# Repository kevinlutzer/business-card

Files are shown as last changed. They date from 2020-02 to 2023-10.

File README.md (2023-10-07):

# Electronic Business Card 

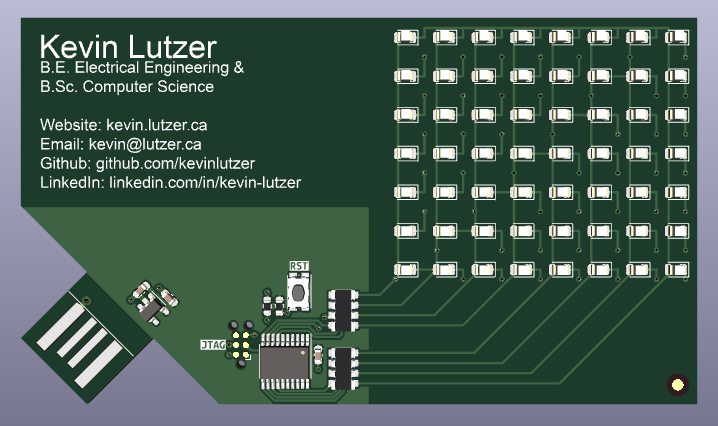
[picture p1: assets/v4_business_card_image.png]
V4 Business Card


The purpose of this project was to demonstrate some of my skills as an Electrical Engineer to potential employers. This project required me to build and prototype a tri-state circuit, add controls with a STM32G ARM microcontroller and design/manufacture a custom printed circuit board. When you plug the device into a standard USB2A port it scrolls my portfolio website's URL across the matrix display. I designed this device to cost about $2.50 CAD per populated board. 

This idea was inspired by a piece of advice that Dave Jones, the owner of the [EEVblog](https://www.eevblog.com/) gave. He suggests that engineers should be bringing something to an interview to show that they can actually design and build things. I sent a later version of this project to Dave Jones with a programmer PCB which he opened on a [Mailbag Segment](https://youtu.be/45C6HFf2kIA?si=SCQMgJs3VvQc_wUq&t=3084). 

Currently I am using the project as a way to test and calibrate a pick and place machine.

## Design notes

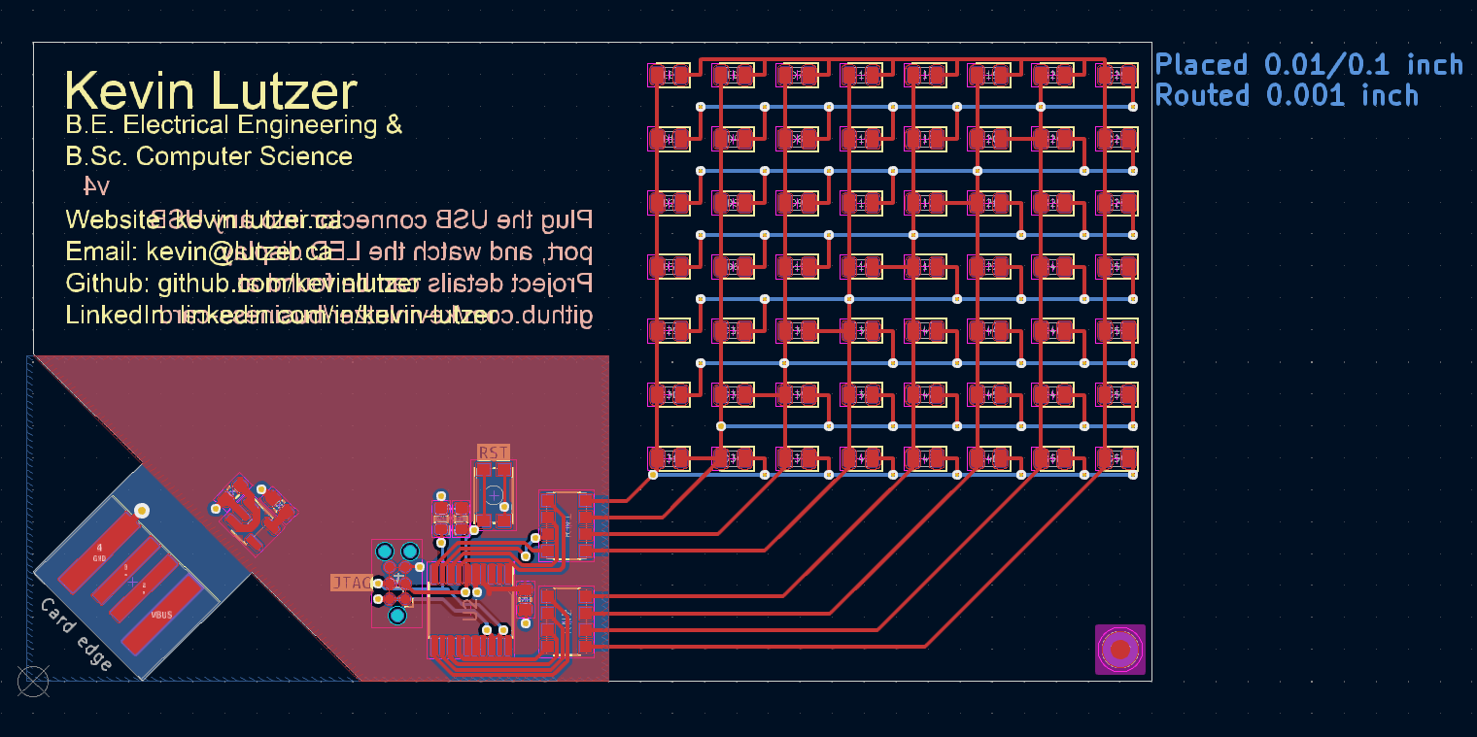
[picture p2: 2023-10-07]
assets/business_card_v4_layout.png

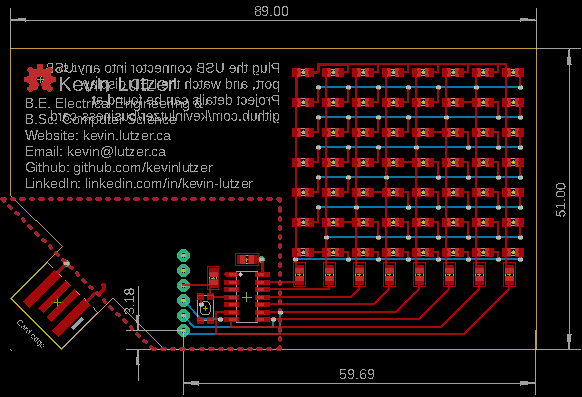
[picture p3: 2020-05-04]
assets/business_card.png

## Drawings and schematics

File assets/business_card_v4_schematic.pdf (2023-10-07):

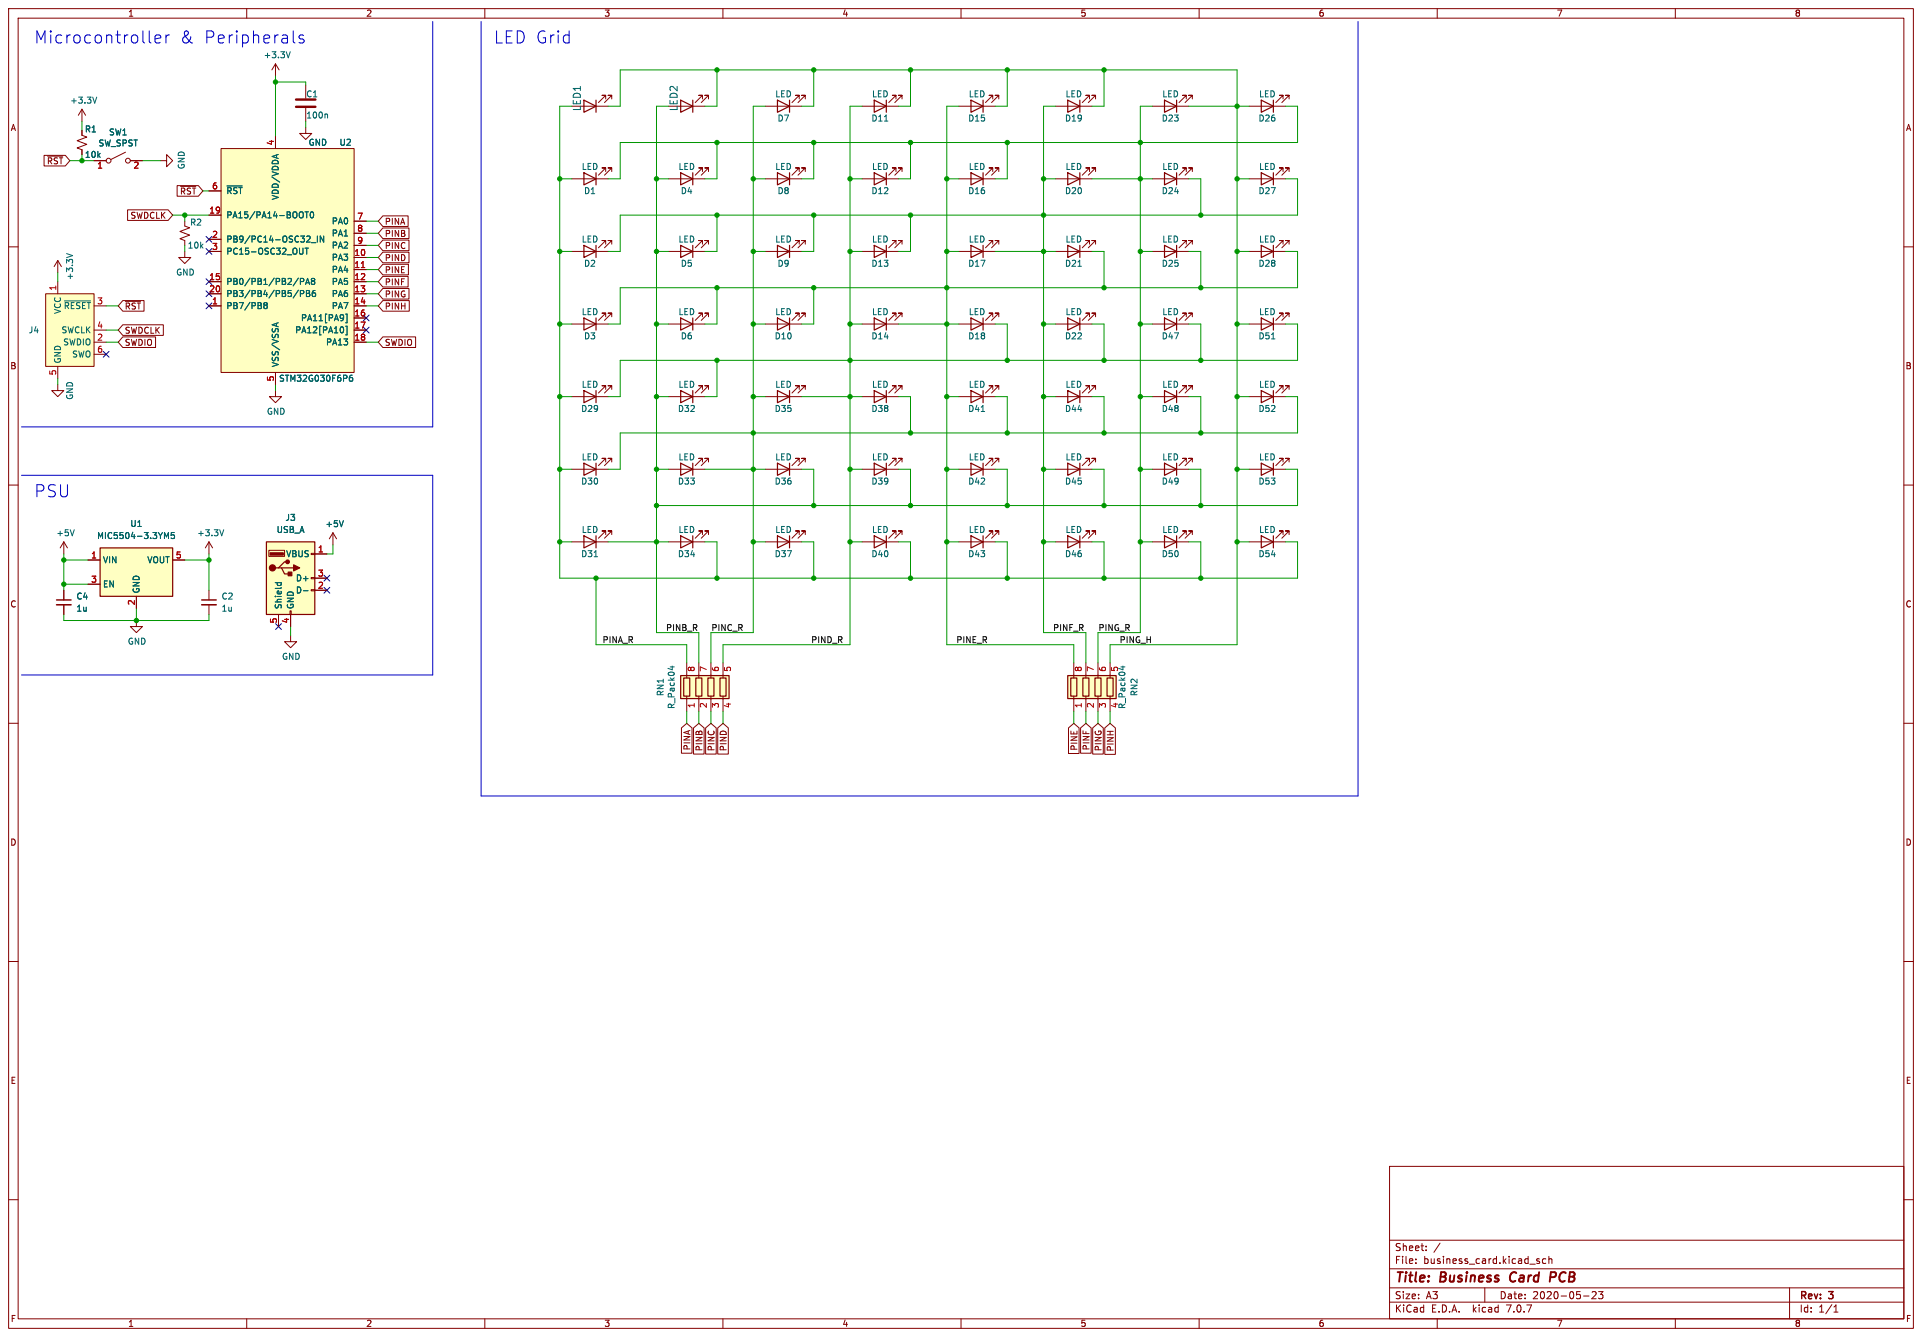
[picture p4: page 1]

1 SWDIO 2 ~{RESET}3 SWCLK 4 GND
LED VCC

Id: 1/1 Title: Business Card PCB

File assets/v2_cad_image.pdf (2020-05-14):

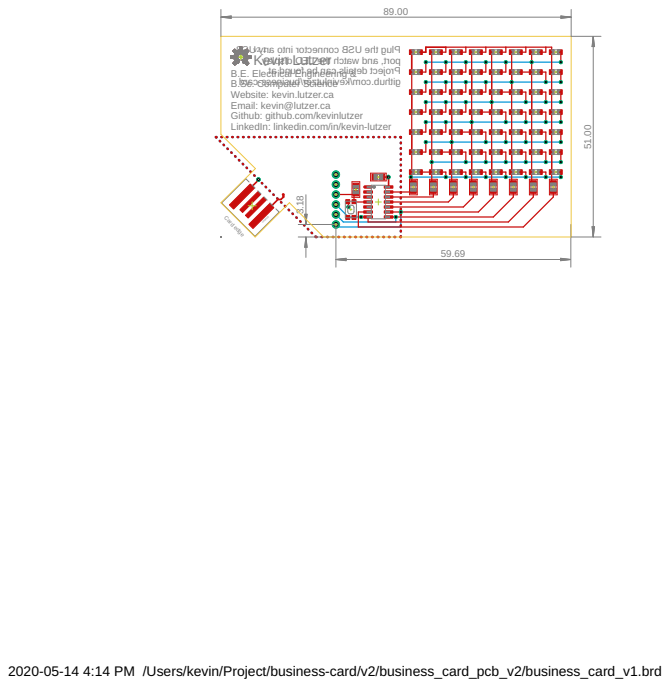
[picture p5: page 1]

B.E. Electrical Engineering &
B.Sc. Computer Science Website: kevin.lutzer.ca Email: kevin@lutzer.ca Github: github.com/kevinlutzer LinkedIn: linkedin.com/in/kevin-lutzer

2020-05-14 4:14 PM /Users/kevin/Project/business-card/v2/business_card_pcb_v2/business_card_v1.brd

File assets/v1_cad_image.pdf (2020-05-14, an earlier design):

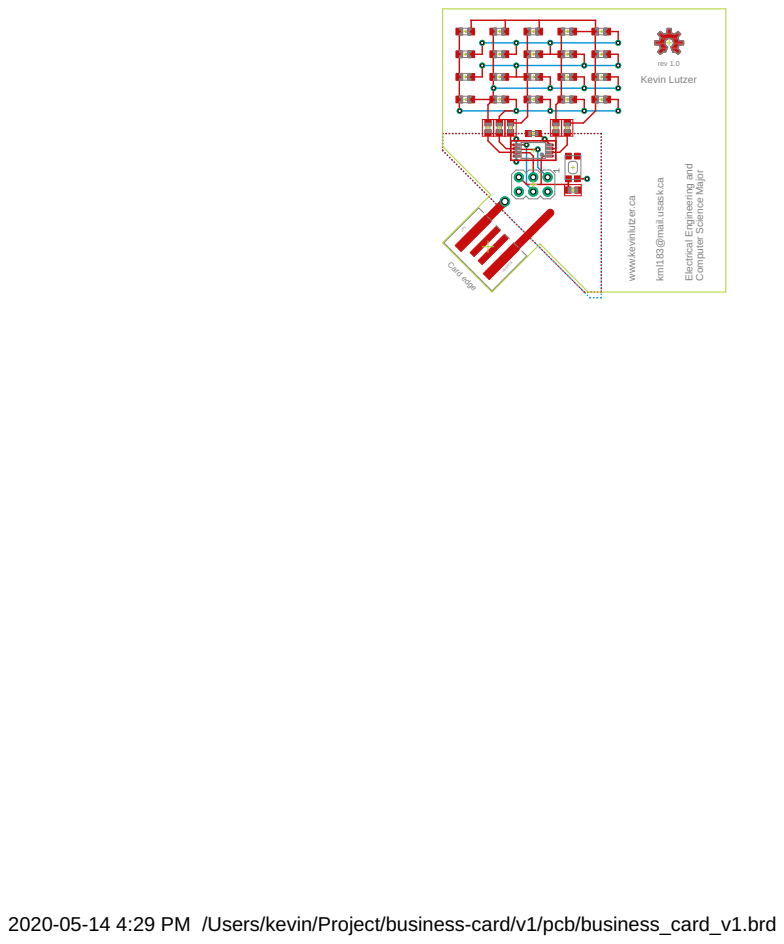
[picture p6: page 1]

kml183@mail.usask.ca Electrical Engineering and Computer Science Major

2020-05-14 4:29 PM /Users/kevin/Project/business-card/v1/pcb/business_card_v1.brd

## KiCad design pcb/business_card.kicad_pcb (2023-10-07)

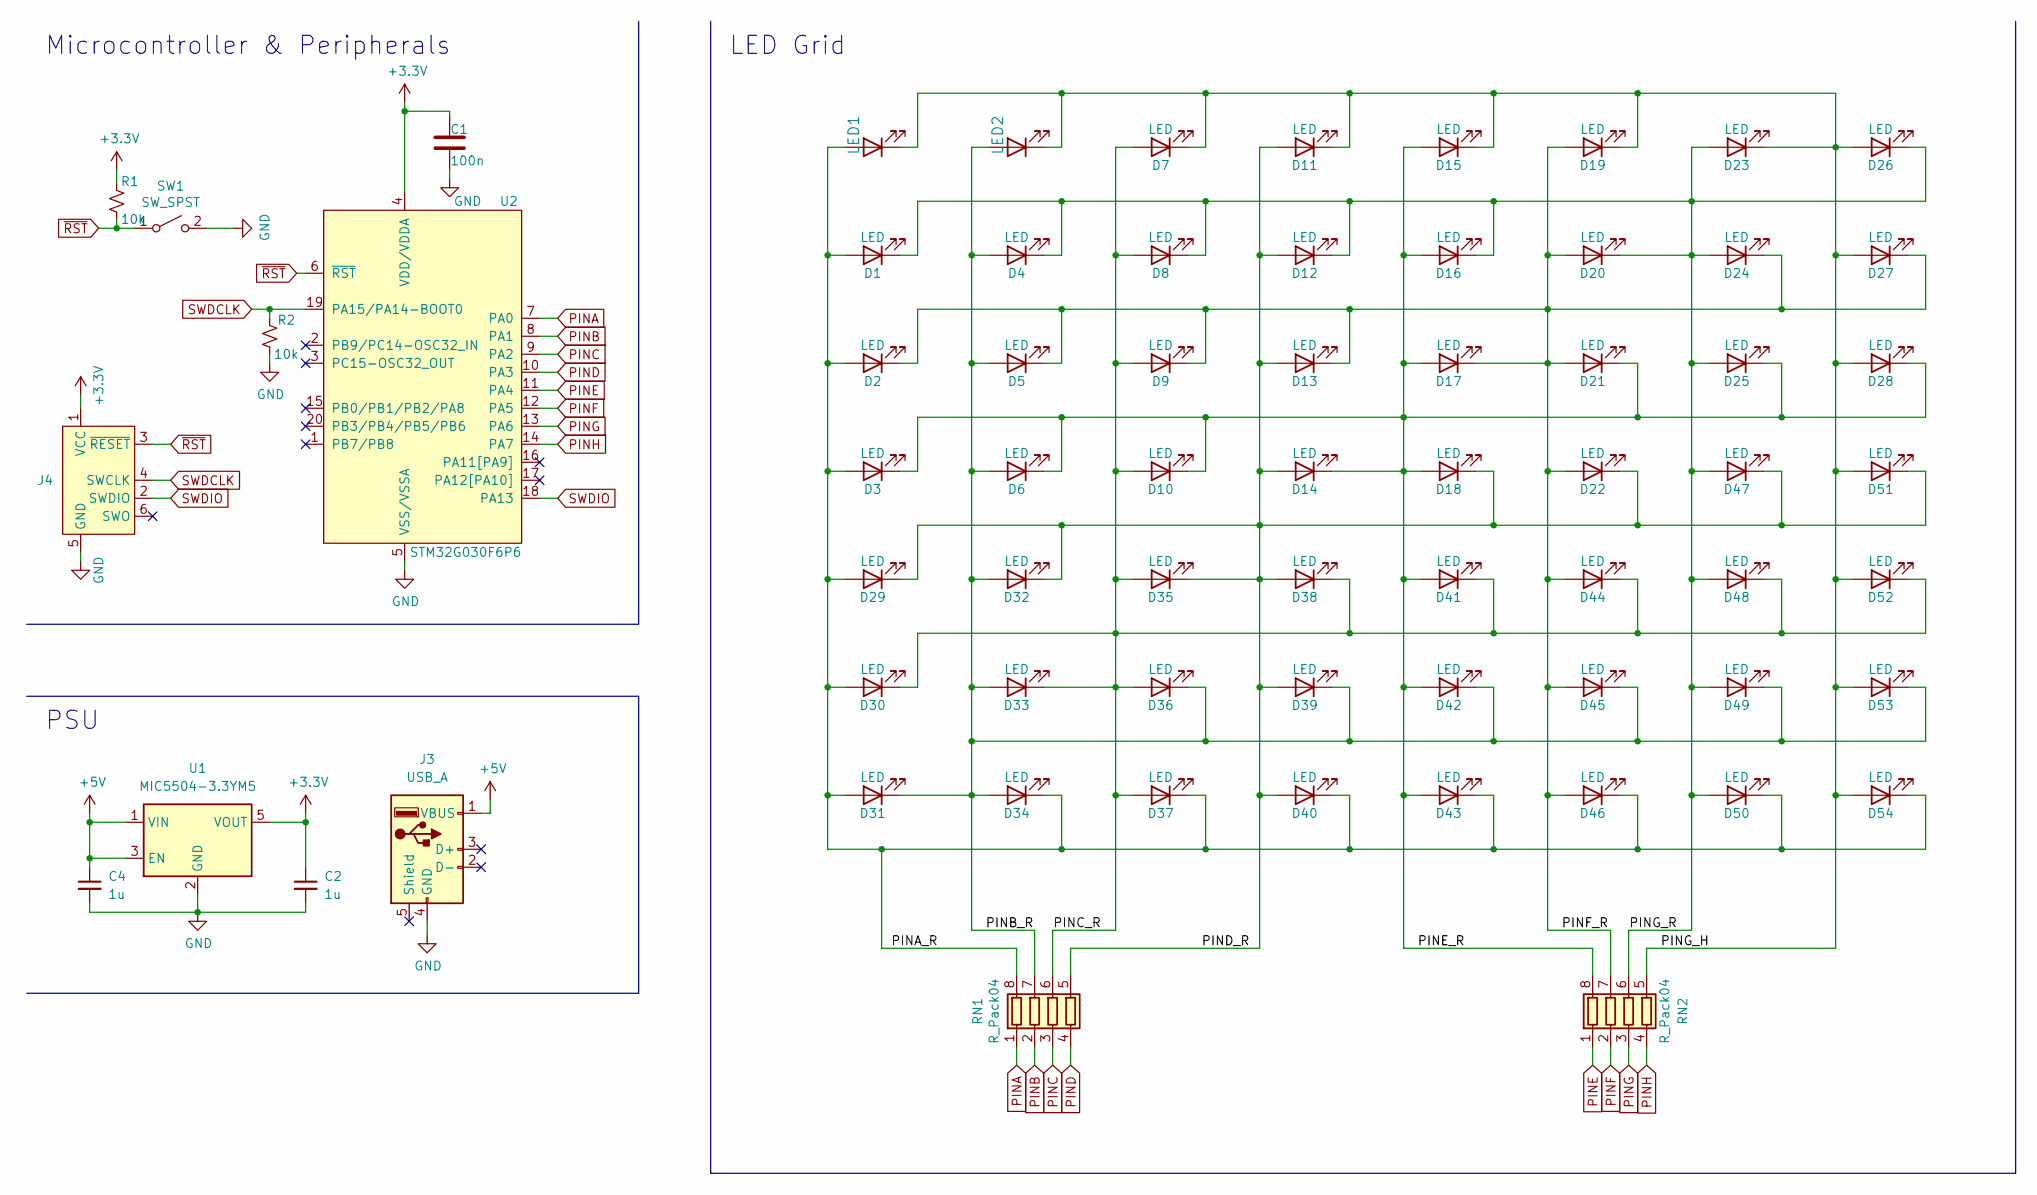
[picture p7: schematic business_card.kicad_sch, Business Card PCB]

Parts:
C1: 100n; C_0603_1608Metric
C2, C4: 1u; C_0603_1608Metric
D1, D2, D3, D4, D5, D6, D7, D8, D9, D10, D11, D12, D13, D14, D15, D16, D17, D18, D19, D20, D21, D22, D23, D24, D25, D26, D27, D28, D29, D30, D31, D32, D33, D34, D35, D36, D37, D38, D39, D40, D41, D42, D43, D44, D45, D46, D47, D48, D49, D50, D51, D52, D53, D54: LED; LED_0805_2012Metric
J3: USB_A; USB_A_PCB
J4: Conn_ARM_SWD_TagConnect_TC2030; Tag-Connect_TC2030-IDC-NL_2x03_P1.27mm_Vertical
LED1: LED; LED_0805_2012Metric
LED2: LED; D_0805_2012Metric
R1, R2: 10k; R_0603_1608Metric
RN1, RN2: R_Pack04; R_Array_Convex_4x1206
SW1: SW_SPST; SW_Push_1P1T_NO_CK_KMR2
U1: MIC5504-3.3YM5; SOT-23-5
U2: STM32G030F6P6; TSSOP-20_4.4x6.5mm_P0.65mm

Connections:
+3V3: C1.1, C2.1, J4.1 (VCC), R1.1, U1.5 (VOUT), U2.4 (VDD/VDDA)
+5V: C4.1, J3.1 (VBUS), U1.1 (VIN), U1.3 (EN)
/PINA_R: D1.2 (A), D2.2 (A), D3.2 (A), D29.2 (A), D30.2 (A), D31.2 (A), D34.1 (K), D37.1 (K), D40.1 (K), D43.1 (K), D46.1 (K), D50.1 (K), D54.1 (K), LED1.2 (A), RN1.8 (R1.2)
/PINB_R: D4.2 (A), D5.2 (A), D6.2 (A), D31.1 (K), D32.2 (A), D33.2 (A), D34.2 (A), D36.1 (K), D39.1 (K), D42.1 (K), D45.1 (K), D49.1 (K), D53.1 (K), LED2.2 (A), RN1.7 (R2.2)
/PINC_R: D7.2 (A), D8.2 (A), D9.2 (A), D10.2 (A), D30.1 (K), D33.1 (K), D35.2 (A), D36.2 (A), D37.2 (A), D38.1 (K), D41.1 (K), D44.1 (K), D48.1 (K), D52.1 (K), RN1.6 (R3.2)
/PIND_R: D11.2 (A), D12.2 (A), D13.2 (A), D14.2 (A), D18.1 (K), D22.1 (K), D29.1 (K), D32.1 (K), D35.1 (K), D38.2 (A), D39.2 (A), D40.2 (A), D47.1 (K), D51.1 (K), RN1.5 (R4.2)
/PINE_R: D3.1 (K), D6.1 (K), D10.1 (K), D14.1 (K), D15.2 (A), D16.2 (A), D17.2 (A), D18.2 (A), D21.1 (K), D25.1 (K), D28.1 (K), D41.2 (A), D42.2 (A), D43.2 (A), RN2.8 (R1.2)
/PINF_R: D2.1 (K), D5.1 (K), D9.1 (K), D13.1 (K), D17.1 (K), D19.2 (A), D20.2 (A), D21.2 (A), D22.2 (A), D24.1 (K), D27.1 (K), D44.2 (A), D45.2 (A), D46.2 (A), RN2.7 (R2.2)
/PING_H: D7.1 (K), D11.1 (K), D15.1 (K), D19.1 (K), D23.1 (K), D26.2 (A), D27.2 (A), D28.2 (A), D51.2 (A), D52.2 (A), D53.2 (A), D54.2 (A), LED1.1 (K), LED2.1 (K), RN2.5 (R4.2)
/PING_R: D1.1 (K), D4.1 (K), D8.1 (K), D12.1 (K), D16.1 (K), D20.1 (K), D23.2 (A), D24.2 (A), D25.2 (A), D26.1 (K), D47.2 (A), D48.2 (A), D49.2 (A), D50.2 (A), RN2.6 (R3.2)
GND: C1.2, C2.2, C4.2, J3.4 (GND), J4.5 (GND), R2.2, SW1.2 (B), U1.2 (GND), U2.5 (VSS/VSSA)
PINA: RN1.1 (R1.1), U2.7 (PA0)
PINB: RN1.2 (R2.1), U2.8 (PA1)
PINC: RN1.3 (R3.1), U2.9 (PA2)
PIND: RN1.4 (R4.1), U2.10 (PA3)
PINE: RN2.1 (R1.1), U2.11 (PA4)
PINF: RN2.2 (R2.1), U2.12 (PA5)
PING: RN2.3 (R3.1), U2.13 (PA6)
PINH: RN2.4 (R4.1), U2.14 (PA7)
SWDCLK: J4.4 (SWCLK), R2.1, U2.19 (PA15/PA14-BOOT0)
SWDIO: J4.2 (SWDIO), U2.18 (PA13)
~RST: J4.3 (~RESET), R1.2, SW1.1 (A), U2.6 (~RST)

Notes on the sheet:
Microcontroller & Peripherals
PSU
LED Grid

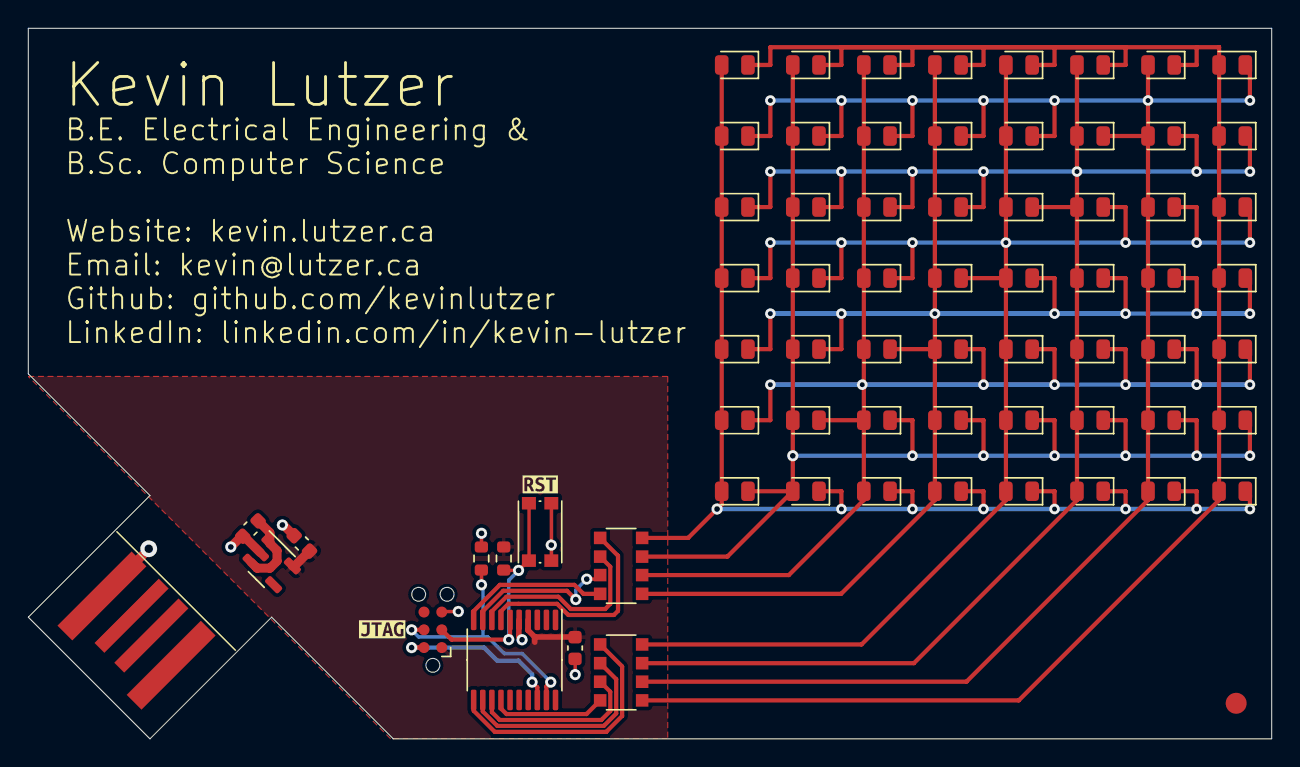
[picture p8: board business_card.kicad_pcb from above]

Board: 2 copper layers, 88.9 x 50.8 mm, 70 parts (0 on the bottom side), 22 nets.

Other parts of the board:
kibuzzard-64BD977B: G***; kibuzzard-64BD977B
kibuzzard-64BD9765: G***; kibuzzard-64BD9765

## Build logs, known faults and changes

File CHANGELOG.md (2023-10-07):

## V4

I added a faducial to the PCB to aid in some experiments I will be running with a pick and place machine. I also swapped out the programming header to use a Tag Connect TC2030 connector footprint. This removes the need for a 0.1 inch programming header or a custom programming PCB. I also switched the design to use a STM32G series process that has an arm core in it. 



## V2

I redesigned the device to use a 7x8 display, this required a larger ATMEL processor as I needed 8 pins to drive the display. Bellow is an image demonstrating what it looks like: 

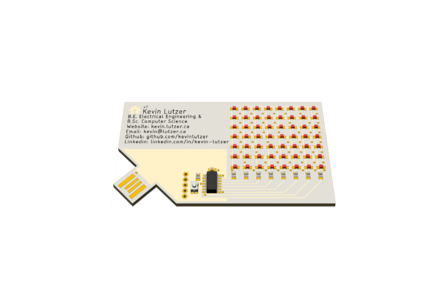
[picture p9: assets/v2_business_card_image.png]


## V1 

The first prototype of this device came in late 2016, early 2017. The image of it operating is below. One of the main problems with this version is that I wasn't able to incorporate the standard 7 bit dot matrix alphabet, so I had to make my own. The result was a display that was hard to read. 

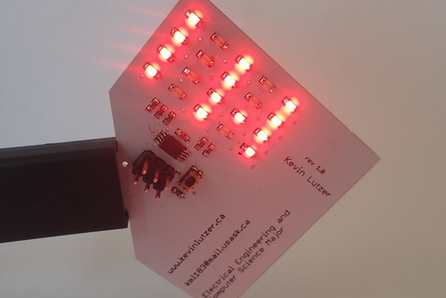
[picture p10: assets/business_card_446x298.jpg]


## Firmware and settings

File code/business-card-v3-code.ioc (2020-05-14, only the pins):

Mcu.UserName=STM32G030F6Px
PA7.Signal=GPIO_Output

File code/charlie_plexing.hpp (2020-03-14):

/*
	Author: Kevin Lutzer
	Created Date: February 3 2016

	Description: Class for controlling a 4X5 led matrix using charlieplexing.
*/

#include <avr/io.h>
#include <util/delay.h>

#define LINEA PA0
#define LINEB PA1
#define LINEC PA2
#define LINED PA3
#define LINEE PA4
#define LINEF PA5
#define LINEG PA6
#define LINEH PA7

#define F_CPU 1000000UL
#define SCROLL_DELAY 100

const uint8_t ncharlieOut[7][8] = {

	// Row 0
	( ( 1 << LINEA ) | ( 0 << LINEH ) ),
	( ( 1 << LINEB ) | ( 0 << LINEH ) ),
	( ( 1 << LINEC ) | ( 0 << LINEH ) ),
	( ( 1 << LINED ) | ( 0 << LINEH ) ),
	( ( 1 << LINEE ) | ( 0 << LINEH ) ),
	( ( 1 << LINEF ) | ( 0 << LINEH ) ), 
	( ( 1 << LINEG ) | ( 0 << LINEH ) ), 
	( ( 1 << LINEH ) | ( 0 << LINEG ) ),

	// Row 1
	( ( 1 << LINEA ) | ( 0 << LINEG ) ),
	( ( 1 << LINEB ) | ( 0 << LINEG ) ),
	( ( 1 << LINEC ) | ( 0 << LINEG ) ),
	( ( 1 << LINED ) | ( 0 << LINEG ) ),
	( ( 1 << LINEE ) | ( 0 << LINEG ) ),
	( ( 1 << LINEF ) | ( 0 << LINEG ) ),
	( ( 1 << LINEG ) | ( 0 << LINEF ) ),
	( ( 1 << LINEH ) | ( 0 << LINEF ) ),

	// Row 2
	( ( 1 << LINEA ) | ( 0 << LINEF ) ),
	( ( 1 << LINEB ) | ( 0 << LINEF ) ),
	( ( 1 << LINEC ) | ( 0 << LINEF ) ),
	( ( 1 << LINED ) | ( 0 << LINEF ) ),
	( ( 1 << LINEE ) | ( 0 << LINEF ) ),
	( ( 1 << LINEF ) | ( 0 << LINEE ) ), 
	( ( 1 << LINEG ) | ( 0 << LINEE ) ), 
	( ( 1 << LINEH ) | ( 0 << LINEE ) ), 

	// Row 3
	( ( 1 << LINEA ) | ( 0 << LINEE ) ),
	( ( 1 << LINEB ) | ( 0 << LINEE ) ),
	( ( 1 << LINEC ) | ( 0 << LINEE ) ),
	( ( 1 << LINED ) | ( 0 << LINEE ) ),
	( ( 1 << LINEE ) | ( 0 << LINED ) ),
	( ( 1 << LINEF ) | ( 0 << LINED ) ), 
	( ( 1 << LINEG ) | ( 0 << LINED ) ), 
	( ( 1 << LINEH ) | ( 0 << LINED ) ), 

	// Row 4
	( ( 1 << LINEA ) | ( 0 << LINED ) ),
	( ( 1 << LINEB ) | ( 0 << LINED ) ),
	( ( 1 << LINEC ) | ( 0 << LINED ) ),
	( ( 1 << LINED ) | ( 0 << LINEC ) ),
	( ( 1 << LINEE ) | ( 0 << LINEC ) ),
	( ( 1 << LINEF ) | ( 0 << LINEC ) ), 
	( ( 1 << LINEG ) | ( 0 << LINEC ) ),
	( ( 1 << LINEH ) | ( 0 << LINEC ) ),

	// Row 5
	( ( 1 << LINEA ) | ( 0 << LINEC ) ),
	( ( 1 << LINEB ) | ( 0 << LINEC ) ),
	( ( 1 << LINEC ) | ( 0 << LINEB ) ), 
	( ( 1 << LINED ) | ( 0 << LINEB ) ),
	( ( 1 << LINEE ) | ( 0 << LINEB ) ),
	( ( 1 << LINEF ) | ( 0 << LINEB ) ),
	( ( 1 << LINEG ) | ( 0 << LINEB ) ), 
	( ( 1 << LINEH ) | ( 0 << LINEB ) ), 

	// Row 6	
	( ( 1 << LINEA ) | ( 0 << LINEB ) ),
	( ( 1 << LINEB ) | ( 0 << LINEA ) ),
	( ( 1 << LINEC ) | ( 0 << LINEA ) ),
	( ( 1 << LINED ) | ( 0 << LINEA ) ),
	( ( 1 << LINEE ) | ( 0 << LINEA ) ),
	( ( 1 << LINEF ) | ( 0 << LINEA ) ),
	( ( 1 << LINEG ) | ( 0 << LINEA ) ), 
	( ( 1 << LINEH ) | ( 0 << LINEA ) ),
};

const uint8_t ncharlieDir[7][8] = {

	// Row 0
	( ( 1 << LINEA ) | ( 1 << LINEH ) ),
	( ( 1 << LINEB ) | ( 1 << LINEH ) ),
	( ( 1 << LINEC ) | ( 1 << LINEH ) ),
	( ( 1 << LINED ) | ( 1 << LINEH ) ),
	( ( 1 << LINEE ) | ( 1 << LINEH ) ),
	( ( 1 << LINEF ) | ( 1 << LINEH ) ), 
	( ( 1 << LINEG ) | ( 1 << LINEH ) ), 
	( ( 1 << LINEH ) | ( 1 << LINEG ) ), 

	// Row 1
	( ( 1 << LINEA ) | ( 1 << LINEG ) ),
	( ( 1 << LINEB ) | ( 1 << LINEG ) ),
	( ( 1 << LINEC ) | ( 1 << LINEG ) ),
	( ( 1 << LINED ) | ( 1 << LINEG ) ),
	( ( 1 << LINEE ) | ( 1 << LINEG ) ),
	( ( 1 << LINEF ) | ( 1 << LINEG ) ),
	( ( 1 << LINEG ) | ( 1 << LINEF ) ),
	( ( 1 << LINEH ) | ( 1 << LINEF ) ),

	// Row 2
	( ( 1 << LINEA ) | ( 1 << LINEF ) ),
	( ( 1 << LINEB ) | ( 1 << LINEF ) ),
	( ( 1 << LINEC ) | ( 1 << LINEF ) ),
	( ( 1 << LINED ) | ( 1 << LINEF ) ),
	( ( 1 << LINEE ) | ( 1 << LINEF ) ),
	( ( 1 << LINEF ) | ( 1 << LINEE ) ), 
	( ( 1 << LINEG ) | ( 1 << LINEE ) ), 
	( ( 1 << LINEH ) | ( 1 << LINEE ) ), 

	// Row 3
	( ( 1 << LINEA ) | ( 1 << LINEE ) ),
	( ( 1 << LINEB ) | ( 1 << LINEE ) ),
	( ( 1 << LINEC ) | ( 1 << LINEE ) ),
	( ( 1 << LINED ) | ( 1 << LINEE ) ),
	( ( 1 << LINEE ) | ( 1 << LINED ) ),
	( ( 1 << LINEF ) | ( 1 << LINED ) ), 
	( ( 1 << LINEG ) | ( 1 << LINED ) ), 
	( ( 1 << LINEH ) | ( 1 << LINED ) ), 

	// Row 4
	( ( 1 << LINEA ) | ( 1 << LINED ) ),
	( ( 1 << LINEB ) | ( 1 << LINED ) ),
	( ( 1 << LINEC ) | ( 1 << LINED ) ),
	( ( 1 << LINED ) | ( 1 << LINEC ) ),
	( ( 1 << LINEE ) | ( 1 << LINEC ) ),
	( ( 1 << LINEF ) | ( 1 << LINEC ) ), 
	( ( 1 << LINEG ) | ( 1 << LINEC ) ),
	( ( 1 << LINEH ) | ( 1 << LINEC ) ),

	// Row 5
	( ( 1 << LINEA ) | ( 1 << LINEC ) ),
	( ( 1 << LINEB ) | ( 1 << LINEC ) ),
	( ( 1 << LINEC ) | ( 1 << LINEB ) ), 
	( ( 1 << LINED ) | ( 1 << LINEB ) ),
	( ( 1 << LINEE ) | ( 1 << LINEB ) ),
	( ( 1 << LINEF ) | ( 1 << LINEB ) ),
	( ( 1 << LINEG ) | ( 1 << LINEB ) ), 
	( ( 1 << LINEH ) | ( 1 << LINEB ) ), 
	
	// Row 6	
	( ( 1 << LINEA ) | ( 1 << LINEB ) ),
	( ( 1 << LINEB ) | ( 1 << LINEA ) ),
	( ( 1 << LINEC ) | ( 1 << LINEA ) ),
	( ( 1 << LINED ) | ( 1 << LINEA ) ),
	( ( 1 << LINEE ) | ( 1 << LINEA ) ),
	( ( 1 << LINEF ) | ( 1 << LINEA ) ),
	( ( 1 << LINEG ) | ( 1 << LINEA ) ), 
	( ( 1 << LINEH ) | ( 1 << LINEA ) ),

};

class CharliePlex{

	public:
		// basic led operations
		void setLed(uint8_t row, uint8_t column);
		void allLedOn();
		void ledOff();

		// scrolling and fram operations
		void scrollLed(bool dir);
		void displayFrame( uint8_t image[][8] );
		void displayRow( uint8_t image[], uint8_t row );
};

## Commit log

2016-05-23 adding code and cad files to the repository
    [business_card_v1.GBL, business_card_v1.GBO, business_card_v1.GBP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]
2016-07-15 deleted lock on .sch file
    [business_card_v1.GBL, business_card_v1.GBO, business_card_v1.GBP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]
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2017-04-01 last commit before computer reset
    [business_card_v1.brd, business_card_v1.sch]
2019-02-21 refactor and put everything in a v1
    [business_card_v1.brd, business_card_v1.sch]
2020-01-19 add the base pcb files for the v2 design
    [business_card_v1.brd, business_card_v1.sch]
2020-02-07 get the led layout right
    [business_card_v1.sch]
2020-02-07 update pcb and schematic
    [business_card_v1.brd, business_card_v1.sch]
2020-02-09 route the led grid, add the silk screen
    [business_card_v1.brd]
2020-02-10 finish of the routing and get personal information on silk screen
    [business_card_v1.brd]
2020-02-10 fix the business card design
    [business_card_v1.brd]
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2020-02-10 get the business card design done, looking for review now
    [business_card_v1.brd, business_card_v1.sch]
2020-02-10 fix some of the silk screen
    [business_card_v1.brd, business_card_v1.sch]
2020-02-10 add the gerber files
    [copper_bottom.gbr, copper_top.gbr, drill_1_16.xln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]
2020-02-11 more silk screen updates
    [business_card_v1.brd]
2020-02-11 get the businss card completed
    [business_card_v1.brd]
2020-02-11 update the 3d models
    [business_card_v1.brd, business_card_v1.sch]
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2020-02-18 get the published version completed
    [business_card_v1.brd]
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2020-03-13 add the pcb boarder
    [pcb_boarder.dxf]
2020-03-14 add the programming enclosure
    [programmer_case.scad]
2020-03-14 add the programmer case base file
    [programmer_case.scad]
2020-03-14 revert some changes to the v1 directory
    [programmer_case.scad]
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2020-03-31 add the programming case
    [programmer_case.scad, programmer_case.stl]
2020-03-31 name change of the business card PCB
    [business_card_v1.brd, business_card_v1.sch]
2020-03-31 add the sck pad pin for miso and mosi
    [business_card_v1.brd, business_card_v1.sch]
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2020-04-01 start populating some of the components
    [programmer_pcb.brd, programmer_pcb.sch]
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2020-04-02 add zip with gerber files
    [programmer_pcb.brd]
2020-05-04 add the v3 version of the pcb
    [business_card_v1.sch, programmer_pcb.brd]
2020-05-05 add the base import of the business card files
    [business_card_v1.kicad_pcb, business_card_v1.sch]
2020-05-07 finish pcb prototype for the card
    [business_card_v1.sch]
2020-05-08 add the final touches to the Pcb
    [business_card_v1-B_Mask.gbr, business_card_v1-B_Paste.gbr, business_card_v1-B_SilkS.gbr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]
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2020-05-09 move everything before business-card-v3-pcb
    [business_card_v1.kicad_pcb, business_card_v1.sch]
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2020-05-09 build out the majority of the board
    [business-card-v3-programmer-board-pcb.kicad_pcb, business-card-v3-programmer-board-pcb.sch]
2020-05-09 finish the pcb design
    [business-card-v3-programmer-board-pcb.kicad_pcb, business-card-v3-programmer-board-pcb.sch]
2020-05-10 move the programmer board files up a level
    [business-card-v3-programmer-board-pcb.kicad_pcb, business-card-v3-programmer-board-pcb.sch]
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2020-05-10 update to use a smaller resistor array
    [business_card_v1-B_Mask.gbr, business_card_v1-B_Paste.gbr, business_card_v1-B_SilkS.gbr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]
2020-05-14 add gerber files for the pcb
    [business_card_v1-B_Mask.gbr, business_card_v1-B_Paste.gbr, business_card_v1-B_SilkS.gbr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]
2020-05-14 move folders around to the top layer
    [business-card-v3-programmer-board-pcb.kicad_pcb, business-card-v3-programmer-board-pcb.sch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]
2020-05-14 rename folders to be more generic
    [business-card-v3-programmer-board-pcb.kicad_pcb, business-card-v3-programmer-board-pcb.sch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]
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2020-05-14 move gerber names around
    [business-card-v3-programmer-board-pcb-B_Cu.gbr, business-card-v3-programmer-board-pcb-B_Mask.gbr, business-card-v3-programmer-board-pcb-B_Paste.gbr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]
2020-05-14 add gerbers for v2 and v3 programmers
    [Other.gbr, business-card-v3-programmer-board-pcb-B_Cu.gbr, business-card-v3-programmer-board-pcb-B_Mask.gbr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]
2020-05-14 remove the v2 and v1 folder
    [business_card_v1.brd, business_card_v1.sch, card_profile.dxf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]
2020-05-14 remove the gerber files
    [business_card_v1-B_Mask.gbr, business_card_v1-B_Paste.gbr, business_card_v1-B_SilkS.gbr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]
2020-05-24 bring back the correct revision of the v3 pcb
    [business-card-v3-programmer-board-pcb-B_Cu.gbr, business-card-v3-programmer-board-pcb-B_Mask.gbr, business-card-v3-programmer-board-pcb-B_Paste.gbr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]
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2020-05-24 remove the gerber folder as I am using one at a different level
    [business_card_v1-B_Mask.gbr, business_card_v1-B_Paste.gbr, business_card_v1-B_SilkS.gbr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]
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2020-05-24 remove the rescue library
    [business_card_v1.kicad_pcb, business_card_v1.sch]
2020-05-24 remove the rescue lib folder
    [business-card-v3-programmer-board-pcb.sch, business_card_v1.kicad_pcb, business_card_v1.sch]
2023-07-24 realign components on 0.01 inch grid, use solely kicad parts not eagle parts
    [business_card_v1.kicad_pcb, business_card_v1.kicad_sch]
2023-07-24 remove the progremmwer and the eagle files, rename everything to just business card
    [business-card-v3-programmer-board-pcb.kicad_pcb, business-card-v3-programmer-board-pcb.sch, business_card.kicad_pcb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]
2023-07-24 make the v4 gerbers and ibom
    [business_card-B_Mask.gbs, business_card-B_Paste.gbp, business_card-B_Silkscreen.gbo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]
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2023-10-07 use the LED footprint instead of diode footprint for LED2
    [business_card.kicad_sch]
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
